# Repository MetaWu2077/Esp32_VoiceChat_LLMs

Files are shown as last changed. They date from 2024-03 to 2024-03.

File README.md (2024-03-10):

# Esp32_VoiceChat_LLMs
esp32 based device, mainly used for voice chat with large language models

bilibili：https://www.bilibili.com/video/BV1Xv421r715/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

微信wechat：espai1024 

a4
a2
a3

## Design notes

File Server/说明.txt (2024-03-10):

用flask做服务器，运行app.py。客户端目前设置的端口是5000，可自定义

MP3音乐服务用任意web服务器架设都可以

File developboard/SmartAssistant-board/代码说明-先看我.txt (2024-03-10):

代码中需要填写自己的wifi账号密码、申请的token、自己的API Key和Secret Key（科大讯飞）

鉴权和音乐播放都是用的自己的服务器，相关代码在服务器目录里。

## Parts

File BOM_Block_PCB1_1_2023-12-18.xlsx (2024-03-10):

No. | Quantity | Comment | Designator | Footprint | Value | Manufacturer Part | Manufacturer | Supplier Part | Supplier | Price | 购买链接
1 | 1 | BX-XH2.54-2PWZ | BAT | CONN-TH_2P-P2.50_BX-XH2.54-2PWZ |  | BX-XH2.54-2PWZ | Bossie(博锡) | C18077842 | LCSC |  | 立创商城
2 | 1 | PTS645SH50SMTR92LFS | BOOT | KEY-SMD_4P-L6.0-W6.0-P4.50-LS9.0 |  | PTS645SH50SMTR92LFS | C&amp;K | C221869 | LCSC | 0.20 | https://item.taobao.com/item.htm?_u=acp5dt05ff&id=629139420872&skuId=4649810647068
3 | 10 | 100nF | C1,C2,C3,C4,C5,C8,C10,C11,C16,C20 | C0603 | 100nF | CC0603KRX7R9BB104 | YAGEO(国巨) | C14663 | LCSC | 0.08 | https://detail.tmall.com/item.htm?_u=acp5dt19ae&id=41231814882&spm=a1z09.2.0.0.74512e8dfGiFMV
4 | 2 | 220pF | C6,C7 | C0603 | 220pF | CL10B221KB8NNNC | SAMSUNG(三星) | C1603 | LCSC | 0.10
5 | 2 | 10uF | C9,C15 | C0603 | 10uF | CL10A106KP8NNNC | SAMSUNG(三星) | C19702 | LCSC | 0.10
6 | 2 | 1uF | C12,C13 | C0603 | 1uF | CL10A105KB8NNNC | SAMSUNG(三星) | C15849 | LCSC | 0.10
7 | 1 | 10UF16v钽电容A型 | C14 | CAP-SMD_L3.2-W1.6-FD |  | 10UF16v钽电容A型 |  | C9900022791 | LCSC | 0.48 | https://detail.tmall.com/item.htm?_u=acp5dt10d9&id=624584689068&skuId=4420713396714
8 | 2 | 4.7uF | C17,C18 | C0603 | 4.7uF | CL10A475KO8NNNC | SAMSUNG(三星) | C19666 | LCSC | 0.10
9 | 1 | 22uF | C19 | C0603 | 22uF | CL10A226MQ8NRNC | SAMSUNG(三星) | C59461 | LCSC | 0.17
10 | 2 | 1N5819 | D5,D6 | SMA_L4.3-W2.6-LS5.1-RD |  | 1N5819 |  | C9900008009 | LCSC | 0.08 | https://detail.tmall.com/item.htm?_u=acp5dtd98c&id=623683415364&skuId=4409347965773
11 | 2 | SBK160808T-101Y-N | L1,L2 | L0603 |  | SBK160808T-101Y-N | chilisin(奇力新) | C280682 | LCSC |  | 立创商城
12 | 1 | MHT192WDT-ICE | LED1 | LED0603-R-RD_YELLOW |  | MHT192WDT-ICE | MEIHUA(美华) | C389522 | LCSC | 0.18 | https://detail.tmall.com/item.htm?_u=acp5dtf325&id=13860351935&skuId=4107108230741
13 | 1 | NCD0603O1 | LED2 | LED0603-R-RD_YELLOW |  | NCD0603O1 | 国星光电 | C84269 | LCSC | 0.18
14 | 1 | XL-1608UGC-04 | LED3 | LED0603-R-RD_YELLOW |  | XL-1608UGC-04 | XINGLIGHT(成兴光) | C965804 | LCSC | 0.18
15 | 1 | KT-0603R | LED5 | LED0603-R-RD_YELLOW |  | KT-0603R | KENTO | C2286 | LCSC | 0.18
16 | 1 | XL-1608UVC-04 | PWR | LED0603-R-RD_YELLOW |  | XL-1608UVC-04 | XINGLIGHT(成兴光) | C7371898 | LCSC | 0.18
17 | 2 | SS8050-G | Q2,Q4 | SOT-23-3_L2.9-W1.6-P1.90-LS2.8-BR |  | SS8050-G | CJ(江苏长电/长晶) | C164885 | LCSC | 0.05 | https://detail.tmall.com/item.htm?abbucket=9&id=14574984671&ns=1&skuId=4265628094899
18 | 7 | 10kΩ | R1,R2,R5,R6,R7,R8,R15 | R0603 | 10kΩ | 0603WAF1002T5E | UNI-ROYAL(厚声) | C25804 | LCSC | 0.03 | https://detail.tmall.com/item.htm?_u=acp5dtb0c9&id=550090219082&spm=a1z09.2.0.0.74512e8dfGiFMV
19 | 2 | 0Ω | R3,R4 | R0603 | 0Ω | 0603WAF0000T5E | UNI-ROYAL(厚声) | C21189 | LCSC | 0.03
20 | 5 | 5.1kΩ | R9,R10,R11,R12,R17 | R0603 | 5.1kΩ | 0603WAF5101T5E | UNI-ROYAL(厚声) | C23186 | LCSC | 0.03
21 | 1 | 1MΩ | R13 | R0603 | 1MΩ | 0603WAF1004T5E | UNI-ROYAL(厚声) | C22935 | LCSC | 0.03
22 | 1 | 100kΩ | R14 | R0603 | 100kΩ | 0603WAF1003T5E | UNI-ROYAL(厚声) | C25803 | LCSC | 0.03
23 | 1 | 4.7kΩ | R16 | R0603 | 4.7kΩ | 0603WAF4701T5E | UNI-ROYAL(厚声) | C23162 | LCSC | 0.03
24 | 1 | 2kΩ | R18 | R0603 | 2kΩ | 0603WAF2001T5E | UNI-ROYAL(厚声) | C22975 | LCSC | 0.03
25 | 3 | TS24CA | SW1,SW2,SW3 | SW-SMD_TS24CA |  | TS24CA | SHOU HAN(首韩) | C393942 | LCSC | 0.12 | https://detail.tmall.com/item.htm?_u=acp5dt8aa8&id=548649223044&spm=a1z09.2.0.0.74512e8dfGiFMV
26 | 1 | CH340C | U1 | SOP-16_L10.0-W3.9-P1.27-LS6.0-BL |  | CH340C | WCH(南京沁恒) | C84681 | LCSC | 1.10
27 | 1 | ESP32-WROOM-32E-N8 | U2 | WIFI-SMD_ESP32-WROOM-32E |  | ESP32-WROOM-32E-N8 | ESPRESSIF(乐鑫) | C701342 | LCSC | 12.80 | https://detail.tmall.com/item.htm?_u=acp5dtc7fb&id=680483501088&spm=a1z09.2.0.0.74512e8dfGiFMV
28 | 1 | MAX98357AETE+T | U3 | TQFN-16_L3.0-W3.0-P0.50-BL-EP1.5 |  | MAX98357AETE+T | ADI(亚德诺)/MAXIM(美信) | C910544 | LCSC | 1.75 | https://item.taobao.com/item.htm?_u=acp5dteb9d&id=730855604974&skuId=5062624732129
29 | 1 | ICS-43434 | U4 | MIC-SMD_6P-L3.5-W2.7-P0.90-BL |  | ICS-43434 |  | C9900000518 | LCSC | 4.68 | https://item.taobao.com/item.htm?_u=acp5dta0c0&id=696102320967&skuId=5114328355210
30 | 1 | RT9013-33GB | U5 | SOT-23-5_L3.0-W1.7-P0.95-LS2.8-BL |  | RT9013-33GB | RICHTEK(立锜) | C47773 | LCSC | 0.45 | https://detail.tmall.com/item.htm?_u=acp5dt1876&id=640553849054&skuId=4599763948880
31 | 1 | MCP73831T-2ATI/OT | U6 | SOT-23-5_L3.0-W1.7-P0.95-LS2.8-BR |  | MCP73831T-2ATI/OT | MICROCHIP(美国微芯) | C14879 | LCSC | 0.80 | https://item.taobao.com/item.htm?_u=acp5dt6b82&id=745601811630&spm=a1z09.2.0.0.74512e8dfGiFMV
32 | 1 | AO3401A | U7 | SOT-23-3_L2.9-W1.3-P1.90-LS2.4-BR |  | AO3401A | TECH PUBLIC(台舟) | C5122001 | LCSC | 0.17
33 | 1 | TYPE-C 16P QTWT | USB1 | USB-TYPE-C-SMD_TYPE-C-16P-QTWT |  | TYPE-C 16P QTWT | SHOU HAN(首韩) | C5187472 | LCSC | 0.80 | https://detail.tmall.com/item.htm?_u=acp5dtdab3&id=588797413813&skuId=4018827856520
34 | 1 | BX-PH2.0-2PWZ | 喇叭插座 | CONN-TH_2P-P2.00_BX-PH2.0-2PWZ |  | BX-PH2.0-2PWZ | Bossie(博锡) | C18077753 | LCSC |  | 立创商城
35 | 2 | PM254V-11-03-H85 | 开关,开关1 | SW-TH_KH-SS12D11-G5 |  | PM254V-11-03-H85 | XFCN(兴飞) | C541850 | LCSC | 0.40 | https://detail.tmall.com/item.htm?_u=acp5dtfd7c&id=41227706316&skuId=5092010742268
 | 1 | 锂电池1200mah |  |  |  |  |  |  |  | 12.99 | https://item.taobao.com/item.htm?_u=acp5dt4e00&id=615888352047&skuId=5349371343686
 | 1 | 亚克力面板 |  |  |  |  |  |  |  | 1.00 | https://detail.tmall.com/item.htm?_u=acp5dt1b20&id=661703498988&skuId=4946086307520
 | 1 | 小喇叭 |  |  |  |  |  |  |  | 2.00 | https://item.taobao.com/item.htm?_u=acp5dt494d&id=727606749265&skuId=5049497161446
 | 1 | 3D打印外壳 |  |  |  |  |  |  |  | 9.00 | 嘉立创3D打印

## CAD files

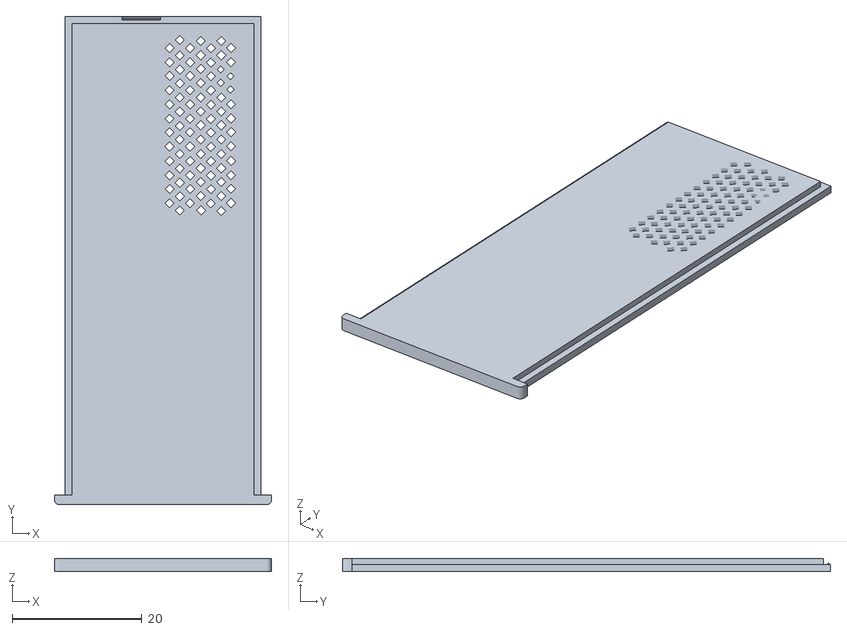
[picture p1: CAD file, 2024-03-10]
shell/whf12-20-T.stl
33.5 x 75.4 x 2.00

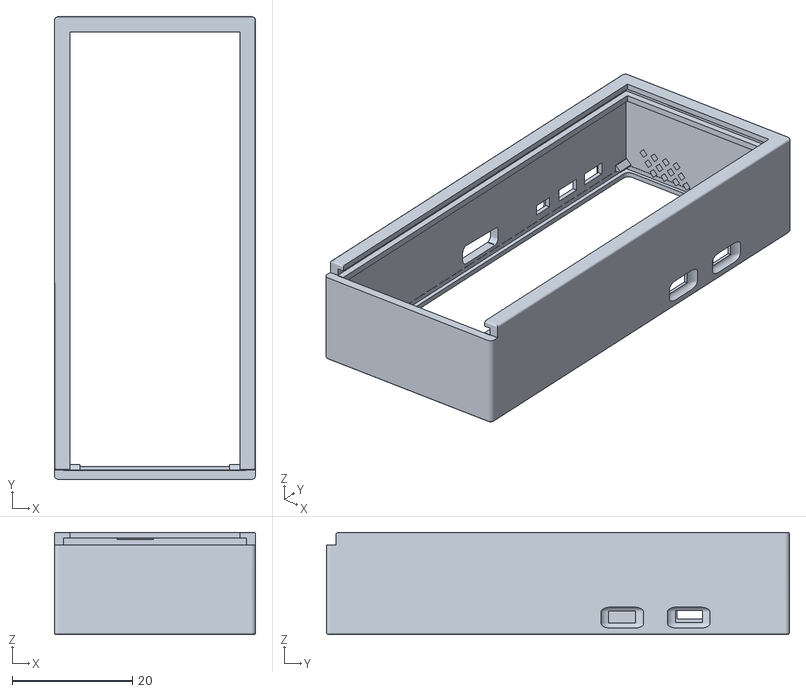
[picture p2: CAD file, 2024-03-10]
shell/whf12-20-B.stl
33.5 x 77.0 x 17.0

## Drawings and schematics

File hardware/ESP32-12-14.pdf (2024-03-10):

# 麦克风及音频放大模块

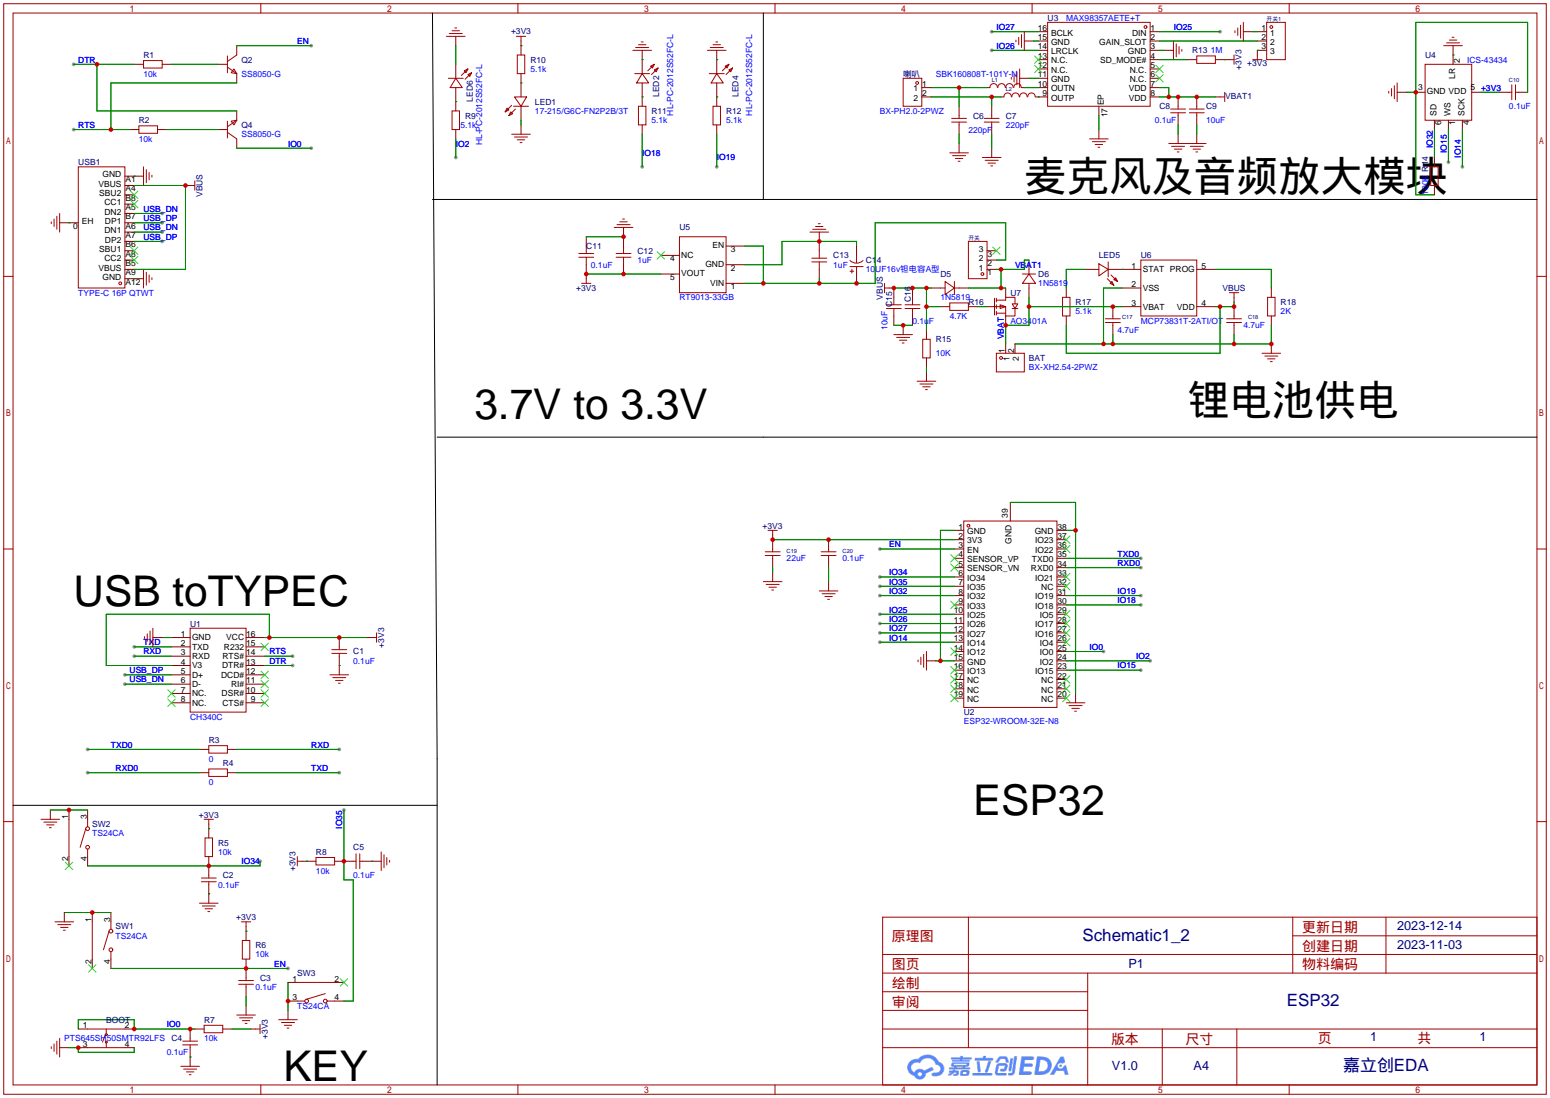
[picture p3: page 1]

U3 MAX98357AETE+T
OUTN 10 GND 11 N.C. 12 N.C. 13 LRCLK 14 GND 15 BCLK 16

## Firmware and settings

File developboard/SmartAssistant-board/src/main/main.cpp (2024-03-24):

#include <Arduino.h>
#include "base64.h"
#include "WiFi.h"
#include <WiFiClientSecure.h>
#include "HTTPClient.h"
#include "Audio1.h"
#include "Audio2.h"
#include <ArduinoJson.h>
#include <ArduinoWebsockets.h>
using namespace websockets;

#define key 0
#define ADC 32
#define led3 2
#define led2 18
#define led1 19
const char *wifiData[][2] = {
    {"111", "11111111"}, // 替换为自己常用的wifi名和密码
    // {"222", "12345678"},
    // 继续添加需要的 Wi-Fi 名称和密码
};

String APPID = " "; // 自己的星火大模型账号参数
String APIKey = " ";
String APISecret = " ";

bool ledstatus = true;
bool startPlay = false;
bool lastsetence = false;
bool isReady = false;
unsigned long urlTime = 0;
unsigned long pushTime = 0;
int mainStatus = 0;
int receiveFrame = 0;
int noise = 50;
HTTPClient https;

hw_timer_t *timer = NULL;

uint8_t adc_start_flag = 0;
uint8_t adc_complete_flag = 0;

Audio1 audio1;
Audio2 audio2(false, 3, I2S_NUM_1);

#define I2S_DOUT 27 // DIN
#define I2S_BCLK 26 // BCLK
#define I2S_LRC 25  // LRC

void gain_token(void);
void getText(String role, String content);
void checkLen(JsonArray textArray);
int getLength(JsonArray textArray);
float calculateRMS(uint8_t *buffer, int bufferSize);
void ConnServer();
void ConnServer1();

DynamicJsonDocument doc(4000);
JsonArray text = doc.to<JsonArray>();

String url = "";
String url1 = "";
String Date = "";
DynamicJsonDocument gen_params(const char *appid, const char *domain);

String askquestion = "";
String Answer = "";

const char *appId1 = ""; // 替换为自己的星火大模型参数
const char *domain1 = "generalv3";
const char *websockets_server = "ws://spark-api.xf-yun.com/v3.5/chat";
const char *websockets_server1 = "ws://ws-api.xfyun.cn/v2/iat";
using namespace websockets;

WebsocketsClient webSocketClient;
WebsocketsClient webSocketClient1;

int loopcount = 0;
void onMessageCallback(WebsocketsMessage message)
{
    StaticJsonDocument<4096> jsonDocument;
    DeserializationError error = deserializeJson(jsonDocument, message.data());

    if (!error)
    {
        int code = jsonDocument["header"]["code"];
        if (code != 0)
        {
            Serial.print("sth is wrong: ");
            Serial.println(code);
            Serial.println(message.data());
            webSocketClient.close();
        }
        else
        {
            receiveFrame++;
            Serial.print("receiveFrame:");
            Serial.println(receiveFrame);
            JsonObject choices = jsonDocument["payload"]["choices"];
            int status = choices["status"];
            const char *content = choices["text"][0]["content"];
            Serial.println(content);
            Answer += content;
            String answer = "";
            if (Answer.length() >= 120 && (audio2.isplaying == 0))
            {
                String subAnswer = Answer.substring(0, 120);
                Serial.print("subAnswer:");
                Serial.println(subAnswer);
                int lastPeriodIndex = subAnswer.lastIndexOf("。");

                if (lastPeriodIndex != -1)
                {
                    answer = Answer.substring(0, lastPeriodIndex + 1);
                    Serial.print("answer: ");
                    Serial.println(answer);
                    Answer = Answer.substring(lastPeriodIndex + 2);
                    Serial.print("Answer: ");
                    Serial.println(Answer);
                    audio2.connecttospeech(answer.c_str(), "zh");
                }
                else
                {
                    const char *chinesePunctuation = "？，：；,.";

                    int lastChineseSentenceIndex = -1;

                    for (int i = 0; i < Answer.length(); ++i)
                    {
                        char currentChar = Answer.charAt(i);

                        if (strchr(chinesePunctuation, currentChar) != NULL)
                        {
                            lastChineseSentenceIndex = i;
                        }
                    }
                    if (lastChineseSentenceIndex != -1)
                    {
                        answer = Answer.substring(0, lastChineseSentenceIndex + 1);
                        audio2.connecttospeech(answer.c_str(), "zh");
                        Answer = Answer.substring(lastChineseSentenceIndex + 2);
                    }
                    else
                    {
                        answer = Answer.substring(0, 120);
                        audio2.connecttospeech(answer.c_str(), "zh");
                        Answer = Answer.substring(120 + 1);
                    }
                }
                startPlay = true;
            }

            if (status == 2)
            {
                getText("assistant", Answer);
                if (Answer.length() <= 80 && (audio2.isplaying == 0))
                {
                    // getText("assistant", Answer);
                    audio2.connecttospeech(Answer.c_str(), "zh");
                }
            }
        }
    }
}

void onEventsCallback(WebsocketsEvent event, String data)
{
    if (event == WebsocketsEvent::ConnectionOpened)
    {
        Serial.println("Send message to server0!");
        DynamicJsonDocument jsonData = gen_params(appId1, domain1);
        String jsonString;
        serializeJson(jsonData, jsonString);
        Serial.println(jsonString);
        webSocketClient.send(jsonString);
    }
    else if (event == WebsocketsEvent::ConnectionClosed)
    {
        Serial.println("Connnection0 Closed");
    }
    else if (event == WebsocketsEvent::GotPing)
    {
        Serial.println("Got a Ping!");
    }
    else if (event == WebsocketsEvent::GotPong)
    {
        Serial.println("Got a Pong!");
    }
}

void onMessageCallback1(WebsocketsMessage message)
{
    StaticJsonDocument<4096> jsonDocument;
    DeserializationError error = deserializeJson(jsonDocument, message.data());

    if (!error)
    {
        int code = jsonDocument["code"];
        if (code != 0)
        {
            Serial.println(code);
            Serial.println(message.data());
            webSocketClient1.close();
        }
        else
        {
            Serial.println("xunfeiyun return message:");
            Serial.println(message.data());
            JsonArray ws = jsonDocument["data"]["result"]["ws"].as<JsonArray>();

            for (JsonVariant i : ws)
            {
                for (JsonVariant w : i["cw"].as<JsonArray>())
                {
                    askquestion += w["w"].as<String>();
                }
            }
            Serial.println(askquestion);
            int status = jsonDocument["data"]["status"];
            if (status == 2)
            {
                Serial.println("status == 2");
                webSocketClient1.close();
                if (askquestion == "")
                {
                    askquestion = "sorry, i can't hear you";
                    audio2.connecttospeech(askquestion.c_str(), "zh");
                }
                else if (askquestion.substring(0, 9) == "唱歌了" or askquestion.substring(0, 9) == "唱歌啦")
                {

                    if (askquestion.substring(0, 12) == "唱歌了，" or askquestion.substring(0, 12) == "唱歌啦，")
                    { // 自建音乐服务器，按照文件名查找对应歌曲
                        String audioStreamURL = "http://192.168.0.1/mp3/" + askquestion.substring(12, askquestion.length() - 3) + ".mp3";
                        Serial.println(audioStreamURL.c_str());
                        audio2.connecttohost(audioStreamURL.c_str());
                    }
                    else if (askquestion.substring(9) == "。")
                    {
                        askquestion = "好啊, 你想听什么歌？";
                        mainStatus = 1;
                        audio2.connecttospeech(askquestion.c_str(), "zh");
                    }
                    else
                    {
                        String audioStreamURL = "http://192.168.0.1/mp3/" + askquestion.substring(9, askquestion.length() - 3) + ".mp3";
                        Serial.println(audioStreamURL.c_str());
                        audio2.connecttohost(audioStreamURL.c_str());
                    }
                }
                else if (mainStatus == 1)
                {
                    askquestion.trim();
                    if (askquestion.endsWith("。"))
                    {
                        askquestion = askquestion.substring(0, askquestion.length() - 3);
                    }
                    else if (askquestion.endsWith(".") or askquestion.endsWith("?"))
                    {
                        askquestion = askquestion.substring(0, askquestion.length() - 1);
                    }
                    String audioStreamURL = "http://192.168.0.1/mp3/" + askquestion + ".mp3";
                    Serial.println(audioStreamURL.c_str());
                    audio2.connecttohost(audioStreamURL.c_str());
                    mainStatus = 0;
                }
                else
                {
                    getText("user", askquestion);
                    Serial.print("text:");
                    Serial.println(text);
                    Answer = "";
                    lastsetence = false;
                    isReady = true;
                    ConnServer();
                }
            }
        }
    }
    else
    {
        Serial.println("error:");
        Serial.println(error.c_str());
        Serial.println(message.data());
    }
}

void onEventsCallback1(WebsocketsEvent event, String data)
{
    if (event == WebsocketsEvent::ConnectionOpened)
    {
        Serial.println("Send message to xunfeiyun");
        digitalWrite(led2, HIGH);
        int silence = 0;
        int firstframe = 1;
        int j = 0;
        int voicebegin = 0;
        int voice = 0;
        DynamicJsonDocument doc(2500);
        while (1)
        {
            doc.clear();
            JsonObject data = doc.createNestedObject("data");
            audio1.Record();
            float rms = calculateRMS((uint8_t *)audio1.wavData[0], 1280);
            printf("%d %f\n", 0, rms);
            if (rms < noise)
            {
                if (voicebegin == 1)
                {
                    silence++;
                    // Serial.print("noise:");
                    // Serial.println(noise);
                }
            }
            else
            {
                voice++;
                if (voice >= 5)
                {
                    voicebegin = 1;
                }
                else
                {
                    voicebegin = 0;
                }
                silence = 0;
            }
            if (silence == 6)
            {
                data["status"] = 2;
                data["format"] = "audio/L16;rate=8000";
                data["audio"] = base64::encode((byte *)audio1.wavData[0], 1280);
                data["encoding"] = "raw";
                j++;

                String jsonString;
                serializeJson(doc, jsonString);

                webSocketClient1.send(jsonString);
                digitalWrite(led2, LOW);
                delay(40);
                break;
            }
            if (firstframe == 1)
            {
                data["status"] = 0;
                data["format"] = "audio/L16;rate=8000";
                data["audio"] = base64::encode((byte *)audio1.wavData[0], 1280);
                data["encoding"] = "raw";
                j++;

                JsonObject common = doc.createNestedObject("common");
                common["app_id"] = appId1;

                JsonObject business = doc.createNestedObject("business");
                business["domain"] = "iat";
                business["language"] = "zh_cn";
                business["accent"] = "mandarin";
                business["vinfo"] = 1;
                business["vad_eos"] = 1000;

                String jsonString;
                serializeJson(doc, jsonString);

                webSocketClient1.send(jsonString);
                firstframe = 0;
                delay(40);
            }
            else
            {
                data["status"] = 1;
                data["format"] = "audio/L16;rate=8000";
                data["audio"] = base64::encode((byte *)audio1.wavData[0], 1280);
                data["encoding"] = "raw";

                String jsonString;
                serializeJson(doc, jsonString);

                webSocketClient1.send(jsonString);
                delay(40);
            }
        }
    }
    else if (event == WebsocketsEvent::ConnectionClosed)
    {
        Serial.println("Connnection1 Closed");
    }
    else if (event == WebsocketsEvent::GotPing)
    {
        Serial.println("Got a Ping!");
    }
    else if (event == WebsocketsEvent::GotPong)
    {
        Serial.println("Got a Pong!");
    }
}
void ConnServer()
{
    Serial.println("url:" + url);

    webSocketClient.onMessage(onMessageCallback);
    webSocketClient.onEvent(onEventsCallback);
    // Connect to WebSocket
    Serial.println("Begin connect to server0......");
    if (webSocketClient.connect(url.c_str()))
    {
        Serial.println("Connected to server0!");
    }
    else
    {
        Serial.println("Failed to connect to server0!");
    }
}

void ConnServer1()
{
    // Serial.println("url1:" + url1);
    webSocketClient1.onMessage(onMessageCallback1);
    webSocketClient1.onEvent(onEventsCallback1);
    // Connect to WebSocket
    Serial.println("Begin connect to server1......");
    if (webSocketClient1.connect(url1.c_str()))
    {
        Serial.println("Connected to server1!");
    }
    else
    {
        Serial.println("Failed to connect to server1!");
    }
}

void voicePlay()
{
    if ((audio2.isplaying == 0) && Answer != "")
    {
        // String subAnswer = "";
        // String answer = "";
        // if (Answer.length() >= 100)
        //     subAnswer = Answer.substring(0, 100);
        // else
        // {
        //     subAnswer = Answer.substring(0);
        //     lastsetence = true;
        //     // startPlay = false;
        // }

        // Serial.print("subAnswer:");
        // Serial.println(subAnswer);
        int firstPeriodIndex = Answer.indexOf("。");
        int secondPeriodIndex = 0;

        if (firstPeriodIndex != -1)
        {
            secondPeriodIndex = Answer.indexOf("。", firstPeriodIndex + 1);
            if (secondPeriodIndex == -1)
                secondPeriodIndex = firstPeriodIndex;
        }
        else
        {
            secondPeriodIndex = firstPeriodIndex;
        }

        if (secondPeriodIndex != -1)
        {
            String answer = Answer.substring(0, secondPeriodIndex + 1);
            Serial.print("answer: ");
            Serial.println(answer);
            Answer = Answer.substring(secondPeriodIndex + 2);
            audio2.connecttospeech(answer.c_str(), "zh");
        }
        else
        {
            const char *chinesePunctuation = "？，：；,.";

            int lastChineseSentenceIndex = -1;

            for (int i = 0; i < Answer.length(); ++i)
            {
                char currentChar = Answer.charAt(i);

                if (strchr(chinesePunctuation, currentChar) != NULL)
                {
                    lastChineseSentenceIndex = i;
                }
            }

            if (lastChineseSentenceIndex != -1)
            {
                String answer = Answer.substring(0, lastChineseSentenceIndex + 1);
                audio2.connecttospeech(answer.c_str(), "zh");
                Answer = Answer.substring(lastChineseSentenceIndex + 2);
            }
        }
        startPlay = true;
    }
    else
    {
        // digitalWrite(led3, LOW);
    }
}

void wifiConnect(const char *wifiData[][2], int numNetworks)
{
    WiFi.disconnect(true);
    for (int i = 0; i < numNetworks; ++i)
    {
        const char *ssid = wifiData[i][0];
        const char *password = wifiData[i][1];

        Serial.print("Connecting to ");
        Serial.println(ssid);

        WiFi.begin(ssid, password);
        uint8_t count = 0;
        while (WiFi.status() != WL_CONNECTED)
        {
            digitalWrite(led1, ledstatus);
            ledstatus = !ledstatus;
            Serial.print(".");
            count++;
            if (count >= 30)
            {
                Serial.printf("\r\n-- wifi connect fail! --");
                break;
            }
            vTaskDelay(100);
        }

        if (WiFi.status() == WL_CONNECTED)
        {
            Serial.printf("\r\n-- wifi connect success! --\r\n");
            Serial.print("IP address: ");
            Serial.println(WiFi.localIP());
            Serial.println("Free Heap: " + String(ESP.getFreeHeap()));
            return; // 如果连接成功，退出函数
        }
    }
}

String getUrl(String Spark_url, String host, String path, String Date)
{

    // 拼接字符串
    String signature_origin = "host: " + host + "\n";
    signature_origin += "date: " + Date + "\n";
    signature_origin += "GET " + path + " HTTP/1.1";
    // signature_origin="host: spark-api.xf-yun.com\ndate: Mon, 04 Mar 2024 19:23:20 GMT\nGET /v3.5/chat HTTP/1.1";

    // hmac-sha256 加密
    unsigned char hmac[32];
    mbedtls_md_context_t ctx;
    mbedtls_md_type_t md_type = MBEDTLS_MD_SHA256;
    const size_t messageLength = signature_origin.length();
    const size_t keyLength = APISecret.length();
    mbedtls_md_init(&ctx);
    mbedtls_md_setup(&ctx, mbedtls_md_info_from_type(md_type), 1);
    mbedtls_md_hmac_starts(&ctx, (const unsigned char *)APISecret.c_str(), keyLength);
    mbedtls_md_hmac_update(&ctx, (const unsigned char *)signature_origin.c_str(), messageLength);
    mbedtls_md_hmac_finish(&ctx, hmac);
    mbedtls_md_free(&ctx);

    // base64 编码
    String signature_sha_base64 = base64::encode(hmac, sizeof(hmac) / sizeof(hmac[0]));

    // 替换Date
    Date.replace(",", "%2C");
    Date.replace(" ", "+");
    Date.replace(":", "%3A");
    String authorization_origin = "api_key=\"" + APIKey + "\", algorithm=\"hmac-sha256\", headers=\"host date request-line\", signature=\"" + signature_sha_base64 + "\"";
    String authorization = base64::encode(authorization_origin);
    String url = Spark_url + '?' + "authorization=" + authorization + "&date=" + Date + "&host=" + host;
    Serial.println(url);
    return url;
}

void getTimeFromServer()
{
    String timeurl = "https://www.baidu.com";
    HTTPClient http;
    http.begin(timeurl);
    const char *headerKeys[] = {"Date"};
    http.collectHeaders(headerKeys, sizeof(headerKeys) / sizeof(headerKeys[0]));
    int httpCode = http.GET();
    Date = http.header("Date");
    Serial.println(Date);
    http.end();
    // delay(50); // 可以根据实际情况调整延时时间
}
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
void loop()
{

    webSocketClient.poll();
    webSocketClient1.poll();
    // delay(10);
    if (startPlay)
    {
        voicePlay();
    }

    audio2.loop();

    if (audio2.isplaying == 1)
    {
        digitalWrite(led3, HIGH);
    }
    else
    {
        digitalWrite(led3, LOW);
        if ((urlTime + 240000 < millis()) && (audio2.isplaying == 0))
        {
            urlTime = millis();
            getTimeFromServer();
            url = getUrl("ws://spark-api.xf-yun.com/v3.5/chat", "spark-api.xf-yun.com", "/v3.5/chat", Date);
            url1 = getUrl("ws://ws-api.xfyun.cn/v2/iat", "ws-api.xfyun.cn", "/v2/iat", Date);
        }
    }

    if (digitalRead(key) == 0)
    {
        audio2.isplaying = 0;
        startPlay = false;
        isReady = false;
        Answer = "";
        Serial.printf("Start recognition\r\n\r\n");

        adc_start_flag = 1;
        // Serial.println(esp_get_free_heap_size());

        if (urlTime + 240000 < millis()) // 超过4分钟，重新做一次鉴权
        {
            urlTime = millis();
            getTimeFromServer();
            url = getUrl("ws://spark-api.xf-yun.com/v3.5/chat", "spark-api.xf-yun.com", "/v3.5/chat", Date);
            url1 = getUrl("ws://ws-api.xfyun.cn/v2/iat", "ws-api.xfyun.cn", "/v2/iat", Date);
        }
        askquestion = "";
        // audio2.connecttospeech(askquestion.c_str(), "zh");
        ConnServer1();
        // ConnServer();
        // delay(6000);
        // audio1.Record();
        adc_complete_flag = 0;

        // Serial.println(text);
        // checkLen(text);
    }
}

void getText(String role, String content)
{
    checkLen(text);
    DynamicJsonDocument jsoncon(1024);
    jsoncon["role"] = role;
    jsoncon["content"] = content;
    text.add(jsoncon);
    jsoncon.clear();
    String serialized;
    serializeJson(text, serialized);
    Serial.print("text: ");
    Serial.println(serialized);
    // serializeJsonPretty(text, Serial);
}

int getLength(JsonArray textArray)
{
    int length = 0;
    for (JsonObject content : textArray)
    {
        const char *temp = content["content"];
        int leng = strlen(temp);
        length += leng;
    }
    return length;
}

void checkLen(JsonArray textArray)
{
    while (getLength(textArray) > 3000)
    {
        textArray.remove(0);
    }
    // return textArray;
}

DynamicJsonDocument gen_params(const char *appid, const char *domain)
{
    DynamicJsonDocument data(2048);

    JsonObject header = data.createNestedObject("header");
    header["app_id"] = appid;
    header["uid"] = "1234";

    JsonObject parameter = data.createNestedObject("parameter");
    JsonObject chat = parameter.createNestedObject("chat");
    chat["domain"] = domain;
    chat["temperature"] = 0.5;
    chat["max_tokens"] = 1024;

    JsonObject payload = data.createNestedObject("payload");
    JsonObject message = payload.createNestedObject("message");

    JsonArray textArray = message.createNestedArray("text");
    for (const auto &item : text)
    {
        textArray.add(item);
    }
    return data;
}

float calculateRMS(uint8_t *buffer, int bufferSize)
{
    float sum = 0;
    int16_t sample;

    for (int i = 0; i < bufferSize; i += 2)
    {

        sample = (buffer[i + 1] << 8) | buffer[i];
        sum += sample * sample;
    }

    sum /= (bufferSize / 2);

    return sqrt(sum);
}

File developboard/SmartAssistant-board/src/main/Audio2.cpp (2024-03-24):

/*
 * Audio2.cpp
 *
 *  Created on: Oct 26.2018
 *
 *  Version 3.0.7
 *  Updated on: Oct 08.2023
 *      Author: Wolle (schreibfaul1)
 *
 */
#include "Audio2.h"
#include "mp3_decoder/mp3_decoder.h"

//---------------------------------------------------------------------------------------------------------------------
AudioBuffer::AudioBuffer(size_t maxBlockSize)
{
    // if maxBlockSize isn't set use defaultspace (1600 bytes) is enough for aac and mp3 player
    if (maxBlockSize)
        m_resBuffSizeRAM = maxBlockSize;
    if (maxBlockSize)
        m_maxBlockSize = maxBlockSize;
}

AudioBuffer::~AudioBuffer()
{
    if (m_buffer)
        free(m_buffer);
    m_buffer = NULL;
}

void AudioBuffer::setBufsize(int ram, int psram)
{
    if (ram > -1) // -1 == default / no change
        m_buffSizeRAM = ram;
    if (psram > -1)
        m_buffSizePSRAM = psram;
}

size_t AudioBuffer::init()
{
    if (m_buffer)
        free(m_buffer);
    m_buffer = NULL;
    if (psramInit() && m_buffSizePSRAM > 0)
    {
        // PSRAM found, AudioBuffer will be allocated in PSRAM
        m_f_psram = true;
        m_buffSize = m_buffSizePSRAM;
        m_buffer = (uint8_t *)ps_calloc(m_buffSize, sizeof(uint8_t));
        m_buffSize = m_buffSizePSRAM - m_resBuffSizePSRAM;
    }
    if (m_buffer == NULL)
    {
        // PSRAM not found, not configured or not enough available
        m_f_psram = false;
        m_buffer = (uint8_t *)heap_caps_calloc(m_buffSizeRAM, sizeof(uint8_t), MALLOC_CAP_DEFAULT | MALLOC_CAP_INTERNAL);
        m_buffSize = m_buffSizeRAM - m_resBuffSizeRAM;
    }
    if (!m_buffer)
        return 0;
    m_f_init = true;
    resetBuffer();
    return m_buffSize;
}

void AudioBuffer::changeMaxBlockSize(uint16_t mbs)
{
    m_maxBlockSize = mbs;
    return;
}

uint16_t AudioBuffer::getMaxBlockSize()
{
    return m_maxBlockSize;
}

size_t AudioBuffer::freeSpace()
{
    if (m_readPtr >= m_writePtr)
    {
        m_freeSpace = (m_readPtr - m_writePtr);
    }
    else
    {
        m_freeSpace = (m_endPtr - m_writePtr) + (m_readPtr - m_buffer);
    }
    if (m_f_start)
        m_freeSpace = m_buffSize;
    return m_freeSpace - 1;
}

size_t AudioBuffer::writeSpace()
{
    if (m_readPtr >= m_writePtr)
    {
        m_writeSpace = (m_readPtr - m_writePtr - 1); // readPtr must not be overtaken
    }
    else
    {
        if (getReadPos() == 0)
            m_writeSpace = (m_endPtr - m_writePtr - 1);
        else
            m_writeSpace = (m_endPtr - m_writePtr);
    }
    if (m_f_start)
        m_writeSpace = m_buffSize - 1;
    return m_writeSpace;
}

size_t AudioBuffer::bufferFilled()
{
    if (m_writePtr >= m_readPtr)
    {
        m_dataLength = (m_writePtr - m_readPtr);
    }
    else
    {
        m_dataLength = (m_endPtr - m_readPtr) + (m_writePtr - m_buffer);
    }
    return m_dataLength;
}

void AudioBuffer::bytesWritten(size_t bw)
{
    m_writePtr += bw;
    if (m_writePtr == m_endPtr)
    {
        m_writePtr = m_buffer;
    }
    if (bw && m_f_start)
        m_f_start = false;
}

void AudioBuffer::bytesWasRead(size_t br)
{
    m_readPtr += br;
    if (m_readPtr >= m_endPtr)
    {
        size_t tmp = m_readPtr - m_endPtr;
        m_readPtr = m_buffer + tmp;
    }
}

uint8_t *AudioBuffer::getWritePtr()
{
    return m_writePtr;
}

uint8_t *AudioBuffer::getReadPtr()
{
    size_t len = m_endPtr - m_readPtr;
    if (len < m_maxBlockSize)
    {                                                     // be sure the last frame is completed
        memcpy(m_endPtr, m_buffer, m_maxBlockSize - len); // cpy from m_buffer to m_endPtr with len
    }
    return m_readPtr;
}

void AudioBuffer::resetBuffer()
{
    m_writePtr = m_buffer;
    m_readPtr = m_buffer;
    m_endPtr = m_buffer + m_buffSize;
    m_f_start = true;
    // memset(m_buffer, 0, m_buffSize); //Clear Inputbuffer
}

uint32_t AudioBuffer::getWritePos()
{
    return m_writePtr - m_buffer;
}

uint32_t AudioBuffer::getReadPos()
{
    return m_readPtr - m_buffer;
}
//---------------------------------------------------------------------------------------------------------------------
Audio2::Audio2(bool internalDAC /* = false */, uint8_t channelEnabled /* = I2S_DAC_CHANNEL_BOTH_EN */, uint8_t i2sPort)
{

    mutex_audio = xSemaphoreCreateMutex();

    //    build-in-DAC works only with ESP32 (ESP32-S3 has no build-in-DAC)
    //    build-in-DAC last working Arduino Version: 2.0.0-RC2
    //    possible values for channelEnabled are:
    //    I2S_DAC_CHANNEL_DISABLE  = 0,     Disable I2S built-in DAC signals
    //    I2S_DAC_CHANNEL_RIGHT_EN = 1,     Enable I2S built-in DAC right channel, maps to DAC channel 1 on GPIO25
    //    I2S_DAC_CHANNEL_LEFT_EN  = 2,     Enable I2S built-in DAC left  channel, maps to DAC channel 2 on GPIO26
    //    I2S_DAC_CHANNEL_BOTH_EN  = 0x3,   Enable both of the I2S built-in DAC channels.
    //    I2S_DAC_CHANNEL_MAX      = 0x4,   I2S built-in DAC mode max index
#ifdef AUDIO_LOG
    m_f_Log = true;
#endif

#define __malloc_heap_psram(size) \
    heap_caps_malloc_prefer(size, 2, MALLOC_CAP_DEFAULT | MALLOC_CAP_SPIRAM, MALLOC_CAP_DEFAULT | MALLOC_CAP_INTERNAL)

    if (psramInit())
        m_chbufSize = 4096;
    else
        m_chbufSize = 512 + 64;
    m_ibuff = (char *)__malloc_heap_psram(512 + 64);
    m_lastHost = (char *)__malloc_heap_psram(512);
    m_outBuff = (int16_t *)__malloc_heap_psram(2048 * 2 * sizeof(int16_t));
    m_chbuf = (char *)__malloc_heap_psram(m_chbufSize);

    if (!m_chbuf || !m_lastHost || !m_outBuff || !m_ibuff)
        log_e("oom");

#define AUDIO_INFO(...)                \
    {                                  \
        sprintf(m_ibuff, __VA_ARGS__); \
        if (audio_info)                \
            audio_info(m_ibuff);       \
    }

    clientsecure.setInsecure(); // if that can't be resolved update to ESP32 Arduino version 1.0.5-rc05 or higher
    m_f_channelEnabled = channelEnabled;
    m_f_internalDAC = internalDAC;
    // i2s configuration
    m_i2s_num = i2sPort; // i2s port number
    m_i2s_config.sample_rate = 16000;
    m_i2s_config.bits_per_sample = I2S_BITS_PER_SAMPLE_16BIT;
    m_i2s_config.channel_format = I2S_CHANNEL_FMT_RIGHT_LEFT;
    m_i2s_config.intr_alloc_flags = ESP_INTR_FLAG_LEVEL1; // interrupt priority
    m_i2s_config.dma_buf_count = 16;
    m_i2s_config.dma_buf_len = 512;
    m_i2s_config.use_apll = APLL_DISABLE;   // must be disabled in V2.0.1-RC1
    m_i2s_config.tx_desc_auto_clear = true; // new in V1.0.1
    m_i2s_config.fixed_mclk = I2S_PIN_NO_CHANGE;

    if (internalDAC)
    {

#ifdef CONFIG_IDF_TARGET_ESP32 // ESP32S3 has no DAC

        log_i("internal DAC");
        m_i2s_config.mode = (i2s_mode_t)(I2S_MODE_MASTER | I2S_MODE_TX | I2S_MODE_DAC_BUILT_IN);
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

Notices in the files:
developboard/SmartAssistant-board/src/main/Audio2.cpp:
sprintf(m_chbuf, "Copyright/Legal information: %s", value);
